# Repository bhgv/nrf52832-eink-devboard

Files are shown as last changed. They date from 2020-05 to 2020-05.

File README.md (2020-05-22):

designed mainly for custom nrf52832 (E73-2G4M04S1B module) + e-Ink screen based
smart-clock 

Eagle CAD PCB in the /pcb folder

tested with 2 and 4 colors waveshare/goodisplay SPI e-Incs: 2.7", 2.3", 2.9". glass based & flexible

software part (IAR 7.7) with drivers for flexible e-ink 2.9" partially refresh (no black screens between drawings/refreshes), 
graphics, font, etc.
yet it is experimental.

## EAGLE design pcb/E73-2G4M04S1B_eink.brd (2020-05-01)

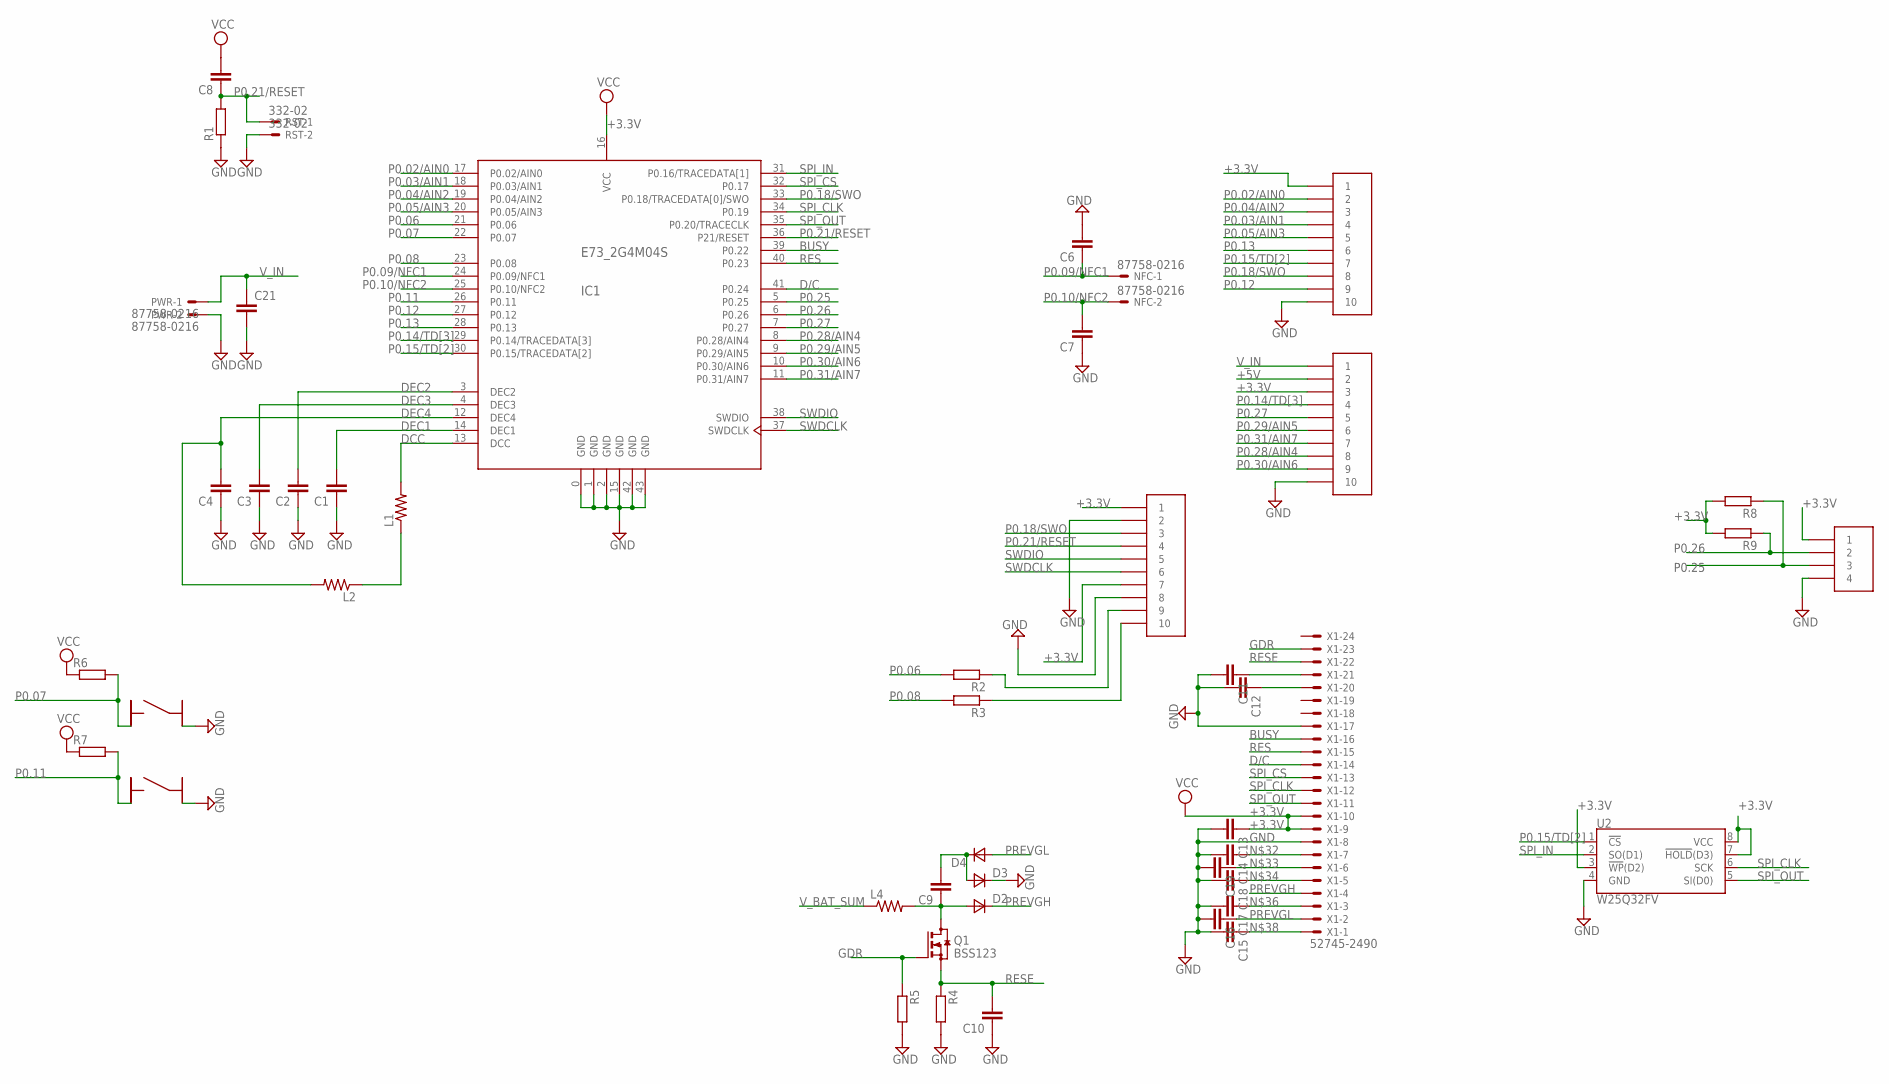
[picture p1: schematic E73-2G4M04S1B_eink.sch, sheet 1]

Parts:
C1, C2, C3, C4, C6, C7, C8, C9, C10, C11, C12, C13, C14, C15, C16, C17, C18, C19: C-EUC0603; C0603
C21: C-EUC0805; C0805
D2, D3, D4: DSOD323; SOD323
DBG-COM, DBG-COM1, DBG-COM2: HDR-1.27MM-110; HDR-1.27MM-1*10
IC1: E73_2G4M04S
L1, L2, L4: R-US_R0805; R0805
NFC: 87758-0216
PWR: 87758-0216
Q1: BSS123; SOT23
R1, R2, R3, R4, R5, R6, R7, R8, R9: R-EU_R0603; R0603
RST: 332-02
U2: W25Q32FV; SOIC-8
U$3: HDR-1.27MM-14; HDR-1.27MM-1*4
U$4, U$5: BUTTON_3X3MM_4PINS; BUT_3X3_4PINS
X1: 52745-2490

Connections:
+3.3V: C8.2, C13.1, DBG-COM.P$1 (1), DBG-COM.P$7 (7), DBG-COM1.P$1 (1), DBG-COM2.P$3 (3), IC1.16 (VCC), R6.1, R7.1, R8.2, R9.2, U2.3 (!WP!(D2)), U2.7 (!HOLD!(D3)), U2.8 (VCC), U$3.P$1 (1), X1.9, X1.10; also elsewhere on the board
+5V: DBG-COM2.P$2 (2); also elsewhere on the board
BUSY: IC1.39 (P0.22), X1.16
D/C: IC1.41 (P0.24), X1.14
DCC: IC1.13 (DCC), L1.2
DEC1: C1.2, IC1.14 (DEC1)
DEC2: C2.2, IC1.3 (DEC2)
DEC3: C3.2, IC1.4 (DEC3)
DEC4: C4.2, IC1.12 (DEC4), L2.2
GDR: Q1.1 (G), R5.1, X1.23
GND: C1.1, C2.1, C3.1, C4.1, C6.2, C7.1, C10.1, C11.2, C12.2, C13.2, C14.2, C15.2, C16.2, C17.2, C18.2, C19.2, C21.2, D3.1 (C), DBG-COM.P$2 (2), DBG-COM.P$8 (8), DBG-COM1.P$10 (10), DBG-COM2.P$10 (10), IC1.0 (GND), IC1.1 (GND), IC1.2 (GND), IC1.15 (GND), IC1.42 (GND), IC1.43 (GND), PWR.2, R1.1, R4.2, R5.2, RST.2, U2.4 (GND), U$3.P$4 (4), U$4.P$2, U$5.P$2, X1.8, X1.17; also elsewhere on the board
unnamed: DBG-COM.P$10 (10), R3.1
unnamed: L1.1, L2.1
unnamed: DBG-COM.P$9 (9), R2.1
unnamed: C9.1, D2.2 (A), L4.2, Q1.3 (D)
unnamed: C9.2, D3.2 (A), D4.1 (C)
unnamed: C11.1, X1.21
unnamed: C12.1, X1.20
unnamed: C14.1, X1.7
unnamed: C19.1, X1.6
unnamed: C18.1, X1.5
unnamed: C17.1, X1.3
unnamed: C15.1, X1.1
P0.02/AIN0: DBG-COM1.P$2 (2), IC1.17 (P0.02/AIN0)
P0.03/AIN1: DBG-COM1.P$4 (4), IC1.18 (P0.03/AIN1)
P0.04/AIN2: DBG-COM1.P$3 (3), IC1.19 (P0.04/AIN2)
P0.05/AIN3: DBG-COM1.P$5 (5), IC1.20 (P0.05/AIN3)
P0.06: IC1.21 (P0.06), R2.2
P0.07: IC1.22 (P0.07), R6.2, U$4.P$1
P0.08: IC1.23 (P0.08), R3.2
P0.09/NFC1: C6.1, IC1.24 (P0.09/NFC1), NFC.1
P0.10/NFC2: C7.2, IC1.25 (P0.10/NFC2), NFC.2
P0.11: IC1.26 (P0.11), R7.2, U$5.P$1
P0.12: DBG-COM1.P$9 (9), IC1.27 (P0.12)
P0.13: DBG-COM1.P$6 (6), IC1.28 (P0.13)
P0.14/TD[3]: DBG-COM2.P$4 (4), IC1.29 (P0.14/TRACEDATA[3])
P0.15/TD[2]: DBG-COM1.P$7 (7), IC1.30 (P0.15/TRACEDATA[2]), U2.1 (!CS!)
P0.18/SWO: DBG-COM.P$3 (3), DBG-COM1.P$8 (8), IC1.33 (P0.18/TRACEDATA[0]/SWO)
P0.21/RESET: C8.1, DBG-COM.P$4 (4), IC1.36 (P21/RESET), R1.2, RST.1
P0.25: IC1.5 (P0.25), R8.1, U$3.P$3 (3)
P0.26: IC1.6 (P0.26), R9.1, U$3.P$2 (2)
P0.27: DBG-COM2.P$5 (5), IC1.7 (P0.27)
P0.28/AIN4: DBG-COM2.P$8 (8), IC1.8 (P0.28/AIN4)
P0.29/AIN5: DBG-COM2.P$6 (6), IC1.9 (P0.29/AIN5)
P0.30/AIN6: DBG-COM2.P$9 (9), IC1.10 (P0.30/AIN6)
P0.31/AIN7: DBG-COM2.P$7 (7), IC1.11 (P0.31/AIN7)
PREVGH: D2.1 (C), X1.4
PREVGL: C16.1, D4.2 (A), X1.2
RES: IC1.40 (P0.23), X1.15
RESE: C10.2, Q1.2 (S), R4.1, X1.22
SPI_CLK: IC1.34 (P0.19), U2.6 (SCK), X1.12
SPI_CS: IC1.32 (P0.17), X1.13
SPI_IN: IC1.31 (P0.16/TRACEDATA[1]), U2.2 (SO(D1))
SPI_OUT: IC1.35 (P0.20/TRACECLK), U2.5 (SI(D0)), X1.11
SWDCLK: DBG-COM.P$6 (6), IC1.37 (SWDCLK)
SWDIO: DBG-COM.P$5 (5), IC1.38 (SWDIO)
V_BAT_SUM: L4.1; also elsewhere on the board
V_IN: C21.1, DBG-COM2.P$1 (1), PWR.1; also elsewhere on the board

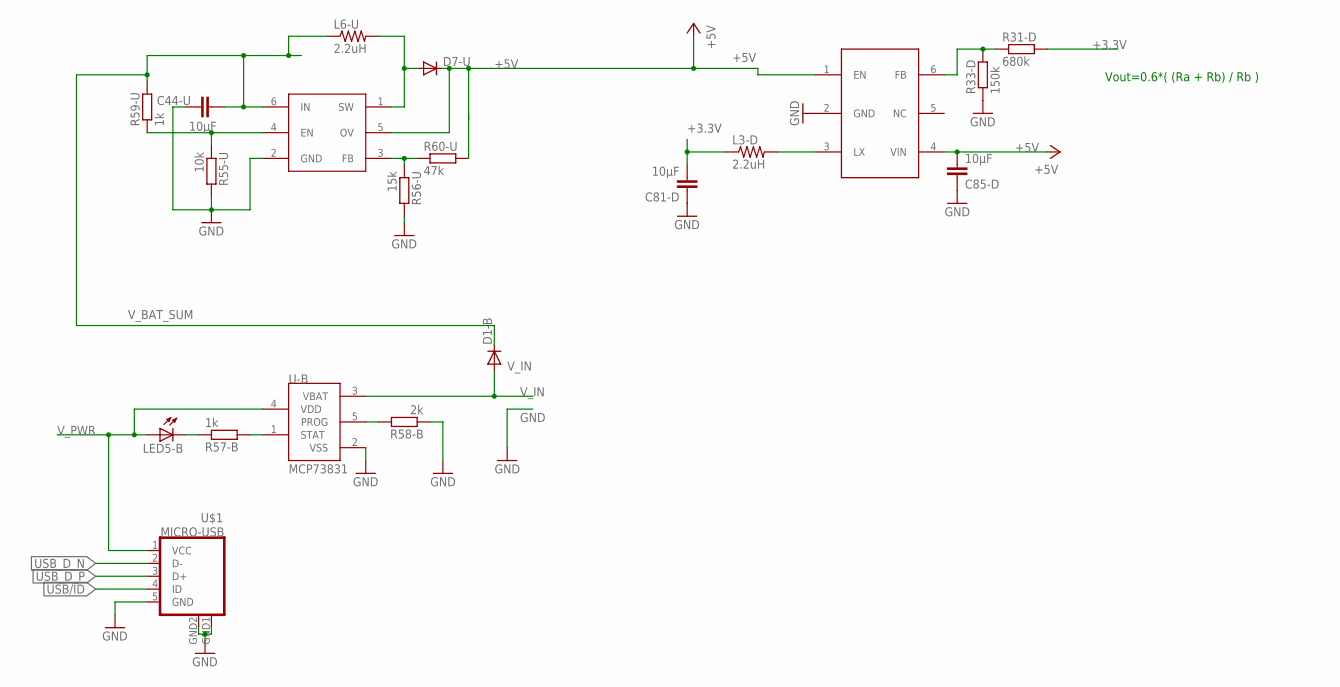
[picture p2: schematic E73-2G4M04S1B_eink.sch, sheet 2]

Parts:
C44-U, C81-D, C85-D: 10µF; C0805
D1-B, D7-U: DIODE-SOD323-W; SOD323-W
L3-D, L6-U: 2.2uH; R0805
LED5-B: LEDCHIPLED_0805; CHIPLED_0805
R31-D: 680k; R0603
R33-D: 150k; R0603
R55-U: 10k; R0603
R56-U: 15k; R0603
R57-B, R59-U: 1k; R0603
R58-B: 2k; R0603
R60-U: 47k; R0603
U$1: MICRO-USB
U-B: MCP73831; SOT23-5L
U-D: STI3411; SOT23-6
U-U: PT4101; SOT23-6

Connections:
+3.3V: C81-D.2, L3-D.1, R31-D.2; also elsewhere on the board
+5V: C85-D.2, D7-U.C, R60-U.2, U-D.1 (EN), U-D.4 (VIN), U-U.5 (OV); also elsewhere on the board
GND: C44-U.2, C81-D.1, C85-D.1, R33-D.1, R55-U.2, R56-U.2, R58-B.1, U$1.5 (GND), U$1.GND1 (GND), U$1.GND2 (GND), U-B.2 (VSS), U-D.2 (GND), U-U.2 (GND); also elsewhere on the board
unnamed: R56-U.1, R60-U.1, U-U.3 (FB)
unnamed: R55-U.1, R59-U.1, U-U.4 (EN)
unnamed: D7-U.A, L6-U.2, U-U.1 (SW)
unnamed: L3-D.2, U-D.3 (LX)
unnamed: R31-D.1, R33-D.2, U-D.6 (FB)
unnamed: R58-B.2, U-B.5 (PROG)
unnamed: R57-B.2, U-B.1 (STAT)
unnamed: LED5-B.C, R57-B.1
USB/ID: U$1.4 (ID)
USB_D_N: U$1.2 (D-)
USB_D_P: U$1.3 (D+)
V_BAT_SUM: C44-U.1, D1-B.C, L6-U.1, R59-U.2, U-U.6 (IN); also elsewhere on the board
V_IN: D1-B.A, U-B.3 (VBAT); also elsewhere on the board
V_PWR: LED5-B.A, U$1.1 (VCC), U-B.4 (VDD)

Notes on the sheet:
Vout=0.6*( (Ra + Rb) / Rb )

Board: 2 copper layers, 67 parts (48 on the bottom side), 67 nets, no tracks yet.

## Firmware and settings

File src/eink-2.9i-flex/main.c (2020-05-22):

/**
 * Copyright (c) 2015 - 2018, Nordic Semiconductor ASA
 *
 * All rights reserved.
 *
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
 * 3. Neither the name of Nordic Semiconductor ASA nor the names of its
 *    contributors may be used to endorse or promote products derived from this
 *    software without specific prior written permission.
 *
 * 4. This software, with or without modification, must only be used with a
 *    Nordic Semiconductor ASA integrated circuit.
 *
 * 5. Any software provided in binary form under this license must not be reverse
 *    engineered, decompiled, modified and/or disassembled.
 *
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
 */
#include "nrf_drv_spi.h"
#include "app_util_platform.h"
#include "nrf_gpio.h"
#include "nrf_delay.h"
#include "boards.h"
#include "app_error.h"
#include <string.h>
#include "nrf_log.h"
#include "nrf_log_ctrl.h"
#include "nrf_log_default_backends.h"

#include "nrf_gpiote.h"
#include "nrf_drv_ppi.h"
#include "nrf_drv_timer.h"
#include "nrf_drv_gpiote.h"

#include "nrf_delay.h"

#include "main.h"

#define COMPRESSED

#include "xbm_font.h"
#include "User/XBM/fonts/DINNextW1G_Light_[58]_xbm_font.h"
#include "User/XBM/fonts/DINNextW1G_Light_[127]_xbm_font.h"

#include "User/XBM/fonts/LCD_[124]_xbm_font.h"


#include "User/XBM/fonts/TMVinograd_[70]_xbm_font.h"
#include "User/XBM/fonts/BNHRDFAN_[50]_xbm_font.h"
#include "User/XBM/fonts/BNKGOTHM_[60]_xbm_font.h"
#include "User/XBM/fonts/GOST_A__[62]_xbm_font.h"

#include "User/XBM/fonts/ACLine_[100]_xbm_font.h"
#include "User/XBM/fonts/BNHRDFAN_[50]_xbm_font.h"
#include "User/XBM/fonts/CaviarDreams_[100]_xbm_font.h"
#include "User/XBM/fonts/Lasco_[100]_xbm_font.h"
#include "User/XBM/fonts/OpenSans_[100]_xbm_font.h"
#include "User/XBM/fonts/Ubuntu_[100]_xbm_font.h"
#include "User/XBM/fonts/Alexander_[100]_xbm_font.h"
#include "User/XBM/fonts/BNHRDMBI_[100]_xbm_font.h"
#include "User/XBM/fonts/DINNextW1G_Light_[127]_xbm_font.h"
#include "User/XBM/fonts/LCD_[100]_xbm_font.h"
#include "User/XBM/fonts/Raleway_[100]_xbm_font.h"
#include "User/XBM/fonts/ALLEGRON_[100]_xbm_font.h"
#include "User/XBM/fonts/BNHRDMOB_[100]_xbm_font.h"
#include "User/XBM/fonts/DINNextW1G_Light_[58]_xbm_font.h"
#include "User/XBM/fonts/LCD_[124]_xbm_font.h"
#include "User/XBM/fonts/RobotoCondensed_[100]_xbm_font.h"
#include "User/XBM/fonts/Bender_[100]_xbm_font.h"
#include "User/XBM/fonts/BNKGOTHM_[100]_xbm_font.h"
#include "User/XBM/fonts/gnyrwn971_[100]_xbm_font.h"
#include "User/XBM/fonts/LEngineer_[100]_xbm_font.h"
#include "User/XBM/fonts/TMVinograd_[100]_xbm_font.h"
#include "User/XBM/fonts/BNHRDFAN_[100]_xbm_font.h"
#include "User/XBM/fonts/BNKGOTHM_[60]_xbm_font.h"
#include "User/XBM/fonts/GOST_A__[100]_xbm_font.h"
#include "User/XBM/fonts/NotoSans_[100]_xbm_font.h"
#include "User/XBM/fonts/TMVinograd_[70]_xbm_font.h"

#include <stdio.h>

//#include "ImageData.h"
#include "User/GUI/GUI_Paint.h"
#include "User/e-Paper/EPD_2in7.h"


#define SPI_INSTANCE  0 /**< SPI instance index. */
static const nrf_drv_spi_t spi = NRF_DRV_SPI_INSTANCE(SPI_INSTANCE);  /**< SPI instance. */
static volatile bool spi_xfer_done = true;  /**< Flag used to indicate that SPI instance completed the transfer. */

#define TEST_STRING "Nordic"
//static uint8_t       m_tx_buf[] = TEST_STRING;           /**< TX buffer. */
static uint8_t       m_rx_buf[sizeof(TEST_STRING) + 1];    /**< RX buffer. */
//static const uint8_t m_length = sizeof(m_tx_buf);        /**< Transfer length. */








////////////////////////////////Picture demonstration///////////////////////////////////
////////////////////////////////////////////////////////////////////////////////////////
//296*128   16 gray picture
const unsigned char gImage_1[18944] = { /* 0X81,0X04,0X28,0X01,0X80,0X00, */
0XFF,0XFF,0XFF,0XFF,0XFF,0XFF,0XFF,0XFF,0XFF,0XFF,0XFF,0XFF,0XFF,0XFF,0XFF,0XFF,
0XFF,0XFF,0XFF,0XFF,0XFF,0XFF,0XFF,0XFF,0XFF,0XFF,0XFF,0XFF,0XFF,0XFF,0XFF,0XFF,
0XFF,0XFF,0XFF,0XFF,0XFF,0XFF,0XFF,0XFF,0XFF,0XFF,0XFF,0XFF,0XFF,0XFF,0XFF,0XFF,
0XFF,0XFF,0XFF,0XFF,0XFF,0XFF,0XFF,0XFF,0XFF,0XFF,0XFF,0XFF,0XFF,0XFF,0XFF,0XFF,
0XFF,0XFF,0XFF,0XFF,0XFF,0XFF,0XFF,0XFF,0XFF,0XFF,0XFF,0XFF,0XFF,0XFF,0XFF,0XFF,
0XFF,0XFF,0XFF,0XFF,0XFF,0XFF,0XFF,0XFF,0XFF,0XFF,0XFF,0XFF,0XFF,0XFF,0XFF,0XFF,
0XFF,0XFF,0XFF,0XFF,0XFF,0XFF,0XFF,0XFF,0XFF,0XFF,0XFF,0XFF,0XFF,0XFF,0XFF,0XFF,
0XFF,0XFF,0XFF,0XFF,0XFF,0XFF,0XFF,0XFF,0XFF,0XFF,0XFF,0XFF,0XFF,0XFF,0XFF,0XFF,
0XFF,0XFF,0XFF,0XFF,0XFF,0XFF,0XFF,0XFF,0XFF,0XFF,0XFF,0XFF,0XFF,0XFF,0XFF,0XFF,
0XFF,0XFF,0XFF,0XFF,0XFF,0XFF,0XFF,0XFF,0XFF,0XFF,0XFF,0XFF,0XFF,0XFF,0XFF,0XFF,
0XFF,0XFF,0XFF,0XFF,0XFF,0XFF,0XFF,0XFF,0XFF,0XFF,0XFF,0XFF,0XFF,0XFF,0XFF,0XFF,
0XFF,0XFF,0XFF,0XFF,0XFF,0XFF,0XFF,0XFF,0XFF,0XFF,0XFF,0XFF,0XFF,0XFF,0XFF,0XFF,
0XFF,0XFF,0XFF,0XFF,0XFF,0XFF,0XFF,0XFF,0XFF,0XFF,0XFF,0XFF,0XFF,0XFF,0XFF,0XFF,
0XFF,0XFF,0XFF,0XFF,0XFF,0XFF,0XFF,0XFF,0XFF,0XFF,0XFF,0XFF,0XFF,0XFF,0XFF,0XFF,
0XFF,0XFF,0XFF,0XFF,0XFF,0XFF,0XFF,0XFF,0XFF,0XFF,0XFF,0XFF,0XFF,0XFF,0XFF,0XFF,
0XFF,0XFF,0XFF,0XFF,0XFF,0XFF,0XFF,0XFF,0XFF,0XFF,0XFF,0XFF,0XFF,0XFF,0XFF,0XFF,
0XFF,0XFF,0XFF,0XFF,0XFF,0XFF,0XFF,0XFF,0XFF,0XFF,0XFF,0XFF,0XFF,0XFF,0XFF,0XFF,
0XFF,0XFF,0XFF,0XFF,0XFF,0XFF,0XFF,0XFF,0XFF,0XFF,0XFF,0XFF,0XFF,0XFF,0XFF,0XFF,
0XFF,0XFF,0XFF,0XFF,0XFF,0XFF,0XFF,0XFF,0XFF,0XFF,0XFF,0XFF,0XFF,0XFF,0XFF,0XFF,
0XFF,0XFF,0XFF,0XFF,0XFF,0XFF,0XFF,0XFF,0XFF,0XFF,0XFF,0XFF,0XFF,0XFF,0XFF,0XFF,
0XFF,0XFF,0XFF,0XFF,0XFF,0XFF,0XFF,0XFF,0XFF,0XFF,0XFF,0XFF,0XFF,0XFF,0XFF,0XFF,
0XFF,0XFF,0XFF,0XFF,0XFF,0XFF,0XFF,0XFF,0XFF,0XFF,0XFF,0XFF,0XFF,0XFF,0XFF,0XFF,
0XFF,0XFF,0XFF,0XFF,0XFF,0XFF,0XFF,0XFF,0XFF,0XFF,0XFF,0XFF,0XFF,0XFF,0XFF,0XFF,
0XFF,0XFF,0XFF,0XFF,0XFF,0XFF,0XFF,0XFF,0XFF,0XFF,0XFF,0XFF,0XFF,0XFF,0XFF,0XFF,
0XFF,0XFF,0XFF,0XFF,0XFF,0XFF,0XFF,0XFF,0XFF,0XFF,0XFF,0XFF,0XFF,0XFF,0XFF,0XFF,
0XFF,0XFF,0XFF,0XFF,0XFF,0XFF,0XFF,0XFF,0XFF,0XFF,0XFF,0XFF,0XFF,0XFF,0XFF,0XFF,
0XFF,0XFF,0XFF,0XFF,0XFF,0XFF,0XFF,0XFF,0XFF,0XFF,0XFF,0XFF,0XFF,0XFF,0XFF,0XFF,
0XFF,0XFF,0XFF,0XFF,0XFF,0XFF,0XFF,0XFF,0XFF,0XFF,0XFF,0XFF,0XFF,0XFF,0XFF,0XFF,
0XFF,0XFF,0XFF,0XFF,0XFF,0XFF,0XFF,0XFF,0XFF,0XFF,0XFF,0XFF,0XFF,0XFF,0XFF,0XFF,
0XFF,0XFF,0XFF,0XFF,0XFF,0XFF,0XFF,0XFF,0XFF,0XFF,0XFF,0XFF,0XFF,0XFF,0XFF,0XFF,
0XFF,0XFF,0XFF,0XFF,0XFF,0XFF,0XFF,0XFF,0XFF,0XFF,0XFF,0XFF,0XFF,0XFF,0XFF,0XFF,
0XFF,0XFF,0XFF,0XFF,0XFF,0XFF,0XFF,0XFF,0XFF,0XFF,0XFF,0XFF,0XFF,0XFF,0XFF,0XFF,
0XFF,0XFF,0XFF,0XFF,0XFF,0XFF,0XFF,0XFF,0XFF,0XFF,0XFF,0XFF,0XFF,0XFF,0XFF,0XFF,
0XFF,0XFF,0XFF,0XFF,0XFF,0XFF,0XFF,0XFF,0XFF,0XFF,0XFF,0XFF,0XFF,0XFF,0XFF,0XFF,
0XFF,0XFF,0XFF,0XFF,0XFF,0XFF,0XFF,0XFF,0XFF,0XFF,0XFF,0XFF,0XFF,0XFF,0XFF,0XFF,
0XFF,0XFF,0XFF,0XFF,0XFF,0XFF,0XFF,0XFF,0XFF,0XFF,0XFF,0XFF,0XFF,0XFF,0XFF,0XFF,
0XFF,0XFF,0XFF,0XFF,0XFF,0XFF,0XFF,0XFF,0XFF,0XFF,0XFF,0XFF,0XFF,0XFF,0XFF,0XFF,
0XFF,0XFF,0XFF,0XFF,0XFF,0XFF,0XFF,0XFF,0XFF,0XFF,0XFF,0XFF,0XFF,0XFF,0XFF,0XFF,
0XFF,0XFF,0XFF,0XFF,0XFF,0XFF,0XFF,0XFF,0XFF,0XFF,0XFF,0XFF,0XFF,0XFF,0XFF,0XFF,
0XFF,0XFF,0XFF,0XFF,0XFF,0XFF,0XFF,0XFF,0XFF,0XFF,0XFF,0XFF,0XFF,0XFF,0XFF,0XFF,
0XFF,0XFF,0XFF,0XFF,0XFF,0XFF,0XFF,0XFF,0XFF,0XFF,0XFF,0XFF,0XFF,0XFF,0XFF,0XFF,
0XFF,0XFF,0XFF,0XFF,0XFF,0XFF,0XFF,0XFF,0XFF,0XFF,0XFF,0XFF,0XFF,0XFF,0XFF,0XFF,
0XFF,0XFF,0XFF,0XFF,0XFF,0XFF,0XFF,0XFF,0XFF,0XFF,0XFF,0XFF,0XFF,0XFF,0XFF,0XFF,
0XFF,0XFF,0XFF,0XFF,0XFF,0XFF,0XFF,0XFF,0XFF,0XFF,0XFF,0XFF,0XFF,0XFF,0XFF,0XFF,
0XFF,0XFF,0XFF,0XFF,0XFF,0XFF,0XFF,0XFF,0XFF,0XFF,0XFF,0XFF,0XFF,0XFF,0XFF,0XFF,
0XFF,0XFF,0XFF,0XFF,0XFF,0XFF,0XFF,0XFF,0XFF,0XFF,0XFF,0XFF,0XFF,0XFF,0XFF,0XFF,
0XFF,0XFF,0XFF,0XFF,0XFF,0XFF,0XFF,0XFF,0XFF,0XFF,0XFF,0XFF,0XFF,0XFF,0XFF,0XFF,
0XFF,0XFF,0XFF,0XFF,0XFF,0XFF,0XFF,0XFF,0XFF,0XFF,0XFF,0XFF,0XFF,0XFF,0XFF,0XFF,
0XFF,0XFF,0XFF,0XFF,0XFF,0XFF,0XFF,0XFF,0XFF,0XFF,0XFF,0XFF,0XFF,0XFF,0XFF,0XFF,
0XFF,0XFF,0XFF,0XFF,0XFF,0XFF,0XFF,0XFF,0XFF,0XFF,0XFF,0XFF,0XFF,0XFF,0XFF,0XFF,
0XFF,0XFF,0XFF,0XFF,0XFF,0XFF,0XFF,0XFF,0XFF,0XFF,0XFF,0XFF,0XFF,0XFF,0XFF,0XFF,
0XFF,0XFF,0XFF,0XFF,0XFF,0XFF,0XFF,0XFF,0XFF,0XFF,0XFF,0XFF,0XFF,0XFF,0XFF,0XFF,
0XFF,0XFF,0XFF,0XFF,0XFF,0XFF,0XFF,0XFF,0XFF,0XFF,0XFF,0XFF,0XFF,0XFF,0XFF,0XFF,
0XFF,0XFF,0XFF,0XFF,0XFF,0XFF,0XFF,0XFF,0XFF,0XFF,0XFF,0XFF,0XFF,0XFF,0XFF,0XFF,
0XFF,0XFF,0XFF,0XFF,0XFF,0XFF,0XFF,0XFF,0XFF,0XFF,0XFF,0XFF,0XFF,0XFF,0XFF,0XFF,
0XFF,0XFF,0XFF,0XFF,0XFF,0XFF,0XFF,0XFF,0XFF,0XFF,0XFF,0XFF,0XFF,0XFF,0XFF,0XFF,
0XFF,0XFF,0XFF,0XFF,0XFF,0XFF,0XFF,0XFF,0XFF,0XFF,0XFF,0XFF,0XFF,0XFF,0XFF,0XFF,
0XFF,0XFF,0XFF,0XFF,0XFF,0XFF,0XFF,0XFF,0XFF,0XFF,0XFF,0XFF,0XFF,0XFF,0XFF,0XFF,
0XFF,0XFF,0XFF,0XFF,0XFF,0XFF,0XFF,0XFF,0XFF,0XFF,0XFF,0XFF,0XFF,0XFF,0XFF,0XFF,
0XFF,0XFF,0XFF,0XFF,0XFF,0XFF,0XFF,0XFF,0XFF,0XFF,0XFF,0XFF,0XFF,0XFF,0XFF,0XFF,
0XFF,0XFF,0XFF,0XFF,0XFF,0XFF,0XFF,0XFF,0XFF,0XFF,0XFF,0XFF,0XFF,0XFF,0XFF,0XFF,
0XFF,0XFF,0XFF,0XFF,0XFF,0XFF,0XFF,0XFF,0XFF,0XFF,0XFF,0XFF,0XFF,0XFF,0XFF,0XFF,
0XFF,0XFF,0XFF,0XFF,0XFF,0XFF,0XFF,0XFF,0XFF,0XFF,0XFF,0XFF,0XFF,0XFF,0XFF,0XFF,
0XFF,0XFF,0XFF,0XFF,0XFF,0XFF,0XFF,0XFF,0XFF,0XFF,0XFF,0XFF,0XFF,0XFF,0XFF,0XFF,
0XFF,0XFF,0XFF,0XFF,0XFF,0XFF,0XFF,0XFF,0XFF,0XFF,0XFF,0XFF,0XFF,0XFF,0XFF,0XFF,
0XFF,0XFF,0XFF,0XFF,0XFF,0XFF,0XFF,0XFF,0XFF,0XFF,0XFF,0XFF,0XFF,0XFF,0XFF,0XFF,
0XFF,0XFF,0XFF,0XFF,0XFF,0XFF,0XFF,0XFF,0XFF,0XFF,0XFF,0XFF,0XFF,0XFF,0XFF,0XFF,
0XFF,0XFF,0XFF,0XFF,0XFF,0XFF,0XFF,0XFF,0XFF,0XFF,0XFF,0XFF,0XFF,0XFF,0XFF,0XFF,
0XFF,0XFF,0XFF,0XFF,0XFF,0XFF,0XFF,0XFF,0XFF,0XFF,0XFF,0XFF,0XFF,0XFF,0XFF,0XFF,
0XFF,0XFF,0XFF,0XFF,0XFF,0XFF,0XFF,0XFF,0XFF,0XFF,0XFF,0XFF,0XFF,0XFF,0XFF,0XFF,
0XFF,0XFF,0XFF,0XFF,0XFF,0XFF,0XFF,0XFF,0XFF,0XFF,0XFF,0XFF,0XFF,0XFF,0XFF,0XFF,
0XFF,0XFF,0XFF,0XFF,0XFF,0XFF,0XFF,0XFF,0XFF,0XFF,0XFF,0XFF,0XFF,0XFF,0XFF,0XFF,
0XFF,0XFF,0XFF,0XFF,0XFF,0XFF,0XFF,0XFF,0XFF,0XFF,0XFF,0XFF,0XFF,0XFF,0XFF,0XFF,
0XFF,0XFF,0XFF,0XFF,0XFF,0XFF,0XFF,0XFF,0XFF,0XFF,0XFF,0XFF,0XFF,0XFF,0XFF,0XFF,
0XFF,0XFF,0XFF,0XFF,0XFF,0XFF,0XFF,0XFF,0XFF,0XFF,0XFF,0XFF,0XFF,0XFF,0XFF,0XFF,
0XFF,0XFF,0XFF,0XFF,0XFF,0XFF,0XFF,0XFF,0XFF,0XFF,0XFF,0XFF,0XFF,0XFF,0XFF,0XFF,
0XFF,0XFF,0XFF,0XFF,0XFF,0XFF,0XFF,0XFF,0XFF,0XFF,0XFF,0XFF,0XFF,0XFF,0XFF,0XFF,
0XFF,0XFF,0XFF,0XFF,0XFF,0XFF,0XFF,0XFF,0XFF,0XFF,0XFF,0XFF,0XFF,0XFF,0XFF,0XFF,
0XFF,0XFF,0XFF,0XFF,0XFF,0XFF,0XFF,0XFF,0XFF,0XFF,0XFF,0XFF,0XFF,0XFF,0XFF,0XFF,
0XFF,0XFF,0XFF,0XFF,0XFF,0XFF,0XFF,0XFF,0XFF,0XFF,0XFF,0XFF,0XFF,0XFF,0XFF,0XFF,
0XFF,0XFF,0XFF,0XFF,0XFF,0XFF,0XFF,0XFF,0XFF,0XFF,0XFF,0XFF,0XFF,0XFF,0XFF,0XFF,
0XFF,0XFF,0XFF,0XFF,0XFF,0XFF,0XFF,0XFF,0XFF,0XFF,0XFF,0XFF,0XFF,0XFF,0XFF,0XFF,
0XFF,0XFF,0XFF,0XFF,0XFF,0XFF,0XFF,0XFF,0XFF,0XFF,0XFF,0XFF,0XFF,0XFF,0XFF,0XFF,
0XFF,0XFF,0XFF,0XFF,0XFF,0XFF,0XFF,0XFF,0XFF,0XFF,0XFF,0XFF,0XFF,0XFF,0XFF,0XFF,
0XFF,0XFF,0XFF,0XFF,0XFF,0XFF,0XFF,0XFF,0XFF,0XFF,0XFF,0XFF,0XFF,0XFF,0XFF,0XFF,
0XFF,0XFF,0XFF,0XFF,0XFF,0XFF,0XFF,0XFF,0XFF,0XFF,0XFF,0XFF,0XFF,0XFF,0XFF,0XFF,
0XFF,0XFF,0XFF,0XFF,0XFF,0XFF,0XFF,0XFF,0XFF,0XFF,0XFF,0XFF,0XFF,0XFF,0XFF,0XFF,
0XFF,0XFF,0XFF,0XFF,0XFF,0XFF,0XFF,0XFF,0XFF,0XFF,0XFF,0XFF,0XFF,0XFF,0XFF,0XFF,
0XFF,0XFF,0XFF,0XFF,0XFF,0XFF,0XFF,0XFF,0XFF,0XFF,0XFF,0XFF,0XFF,0XFF,0XFF,0XFF,
0XFF,0XFF,0XFF,0XFF,0XFF,0XFF,0XFF,0XFF,0XFF,0XFF,0XFF,0XFF,0XFF,0XFF,0XFF,0XFF,
0XFF,0XFF,0XFF,0XFF,0XFF,0XFF,0XFF,0XFF,0XFF,0XFF,0XFF,0XFF,0XFF,0XFF,0XFF,0XFF,
0XFF,0XFF,0XFF,0XFF,0XFF,0XFF,0XFF,0XFF,0XFF,0XFF,0XFF,0XFF,0XFF,0XFF,0XFF,0XFF,
0XFF,0XFF,0XFF,0XFF,0XFF,0XFF,0XFF,0XFF,0XFF,0XFF,0XFF,0XFF,0XFF,0XFF,0XFF,0XFF,
0XFF,0XFF,0XFF,0XFF,0XFF,0XFF,0XFF,0XFF,0XFF,0XFF,0XFF,0XFF,0XFF,0XFF,0XFF,0XFF,
0XFF,0XFF,0XFF,0XFF,0XFF,0XFF,0XFF,0XFF,0XFF,0XFF,0XFF,0XFF,0XFF,0XFF,0XFF,0XFF,
0XFF,0XFF,0XFF,0XFF,0XFF,0XFF,0XFF,0XFF,0XFF,0XFF,0XFF,0XFF,0XFF,0XFF,0XFF,0XFF,
0XFF,0XFF,0XFF,0XFF,0XFF,0XFF,0XFF,0XFF,0XFF,0XFF,0XFF,0XFF,0XFF,0XFF,0XFF,0XFF,
0XFF,0XFF,0XFF,0XFF,0XFF,0XFF,0XFF,0XFF,0XFF,0XFF,0XFF,0XFF,0XFF,0XFF,0XFF,0XFF,
0XFF,0XFF,0XFF,0XFF,0XFF,0XFF,0XFF,0XFF,0XFF,0XFF,0XFF,0XFF,0XFF,0XFF,0XFF,0XFF,
0XFF,0XFF,0XFF,0XFF,0XFF,0XFF,0XFF,0XFF,0XFF,0XFF,0XFF,0XFF,0XFF,0XFF,0XFF,0XFF,
0XFF,0XFF,0XFF,0XFF,0XFF,0XFF,0XFF,0XFF,0XFF,0XFF,0XFF,0XFF,0XFF,0XFF,0XFF,0XFF,
0XFF,0XFF,0XFF,0XFF,0XFF,0XFF,0XFF,0XFF,0XFF,0XFF,0XFF,0XFF,0XFF,0XFF,0XFF,0XFF,
0XFF,0XFF,0XFF,0XFF,0XFF,0XFF,0XFF,0XFF,0XFF,0XFF,0XFF,0XFF,0XFF,0XFF,0XFF,0XFF,
0XFF,0XFF,0XFF,0XFF,0XFF,0XFF,0XFF,0XFF,0XFF,0XFF,0XFF,0XFF,0XFF,0XFF,0XFF,0XFF,
0XFF,0XFF,0XFF,0XFF,0XFF,0XFF,0XFF,0XFF,0XFF,0XFF,0XFF,0XFF,0XFF,0XFF,0XFF,0XFF,
0XFF,0XFF,0XFF,0XFF,0XFF,0XFF,0XFF,0XFF,0XFF,0XFF,0XFF,0XFF,0XFF,0XFF,0XFF,0XFF,
0XFF,0XFF,0XFF,0XFF,0XFF,0XFF,0XFF,0XFF,0XFF,0XFF,0XFF,0XFF,0XFF,0XFF,0XFF,0XFF,
0XFF,0XFF,0XFF,0XFF,0XFF,0XFF,0XFF,0XFF,0XFF,0XFF,0XFF,0XFF,0XFF,0XFF,0XFF,0XFF,
0XFF,0XFF,0XFF,0XFF,0XFF,0XFF,0XFF,0XFF,0XFF,0XFF,0XFF,0XFF,0XFF,0XFF,0XFF,0XFF,
0XFF,0XFF,0XFF,0XFF,0XFF,0XFF,0XFF,0XFF,0XFF,0XFF,0XFF,0XFF,0XFF,0XFF,0XFF,0XFF,
0XFF,0XFF,0XFF,0XFF,0XFF,0XFF,0XFF,0XFF,0XFF,0XFF,0XFF,0XFF,0XFF,0XFF,0XFF,0XFF,
0XFF,0XFF,0XFF,0XFF,0XFF,0XFF,0XFF,0XFF,0XFF,0XFF,0XFF,0XFF,0XFF,0XFF,0XFF,0XFF,
0XFF,0XFF,0XFF,0XFF,0XFF,0XFF,0XFF,0XFF,0XFF,0XFF,0XFF,0XFF,0XFF,0XFF,0XFF,0XFF,
0XFF,0XFF,0XFF,0XFF,0XFF,0XFF,0XFF,0XFF,0XFF,0XFF,0XFF,0XFF,0XFF,0XFF,0XFF,0XFF,
0XFF,0XFF,0XFF,0XFF,0XFF,0XFF,0XFF,0XFF,0XFF,0XFF,0XFF,0XFF,0XFF,0XFF,0XFF,0XFF,
0XFF,0XFF,0XFF,0XFF,0XFF,0XFF,0XFF,0XFF,0XFF,0XFF,0XFF,0XFF,0XFF,0XFF,0XFF,0XFF,
0XFF,0XFF,0XFF,0XFF,0XFF,0XFF,0XFF,0XFF,0XFF,0XFF,0XFF,0XFF,0XFF,0XFF,0XFF,0XFF,
0XFF,0XFF,0XFF,0XFF,0XFF,0XFF,0XFF,0XFF,0XFF,0XFF,0XFF,0XFF,0XFF,0XFF,0XFF,0XFF,
0XFF,0XFF,0XFF,0XFF,0XFF,0XFF,0XFF,0XFF,0XFF,0XFF,0XFF,0XFF,0XFF,0XFF,0XFF,0XFF,
0XFF,0XFF,0XFF,0XFF,0XFF,0XFF,0XFF,0XFF,0XFF,0XFF,0XFF,0XFF,0XFF,0XFF,0XFF,0XFF,
0XFF,0XFF,0XFF,0XFF,0XFF,0XFF,0XFF,0XFF,0XFF,0XFF,0XFF,0XFF,0XFF,0XFF,0XFF,0XFF,
0XFF,0XFF,0XFF,0XFF,0XFF,0XFF,0XFF,0XFF,0XFF,0XFF,0XFF,0XFF,0XFF,0XFF,0XFF,0XFF,
0XFF,0XFF,0XFF,0XFF,0XFF,0XFF,0XFF,0XFF,0XFF,0XFF,0XFF,0XFF,0XFF,0XFF,0XFF,0XFF,
0XFF,0XFF,0XFF,0XFF,0XFF,0XFF,0XFF,0XFF,0XFF,0XFF,0XFF,0XFF,0XFF,0XFF,0XFF,0XFF,
0XFF,0XFF,0XFF,0XFF,0XFF,0XFF,0XFF,0XFF,0XFF,0XFF,0XFF,0XFF,0XFF,0XFF,0XFF,0XFF,
0XFF,0XFF,0XFF,0XFF,0XFF,0XFF,0XFF,0XFF,0XFF,0XFF,0XFF,0XFF,0XFF,0XFF,0XFF,0XFF,
0XFF,0XFF,0XFF,0XFF,0XFF,0XFF,0XFF,0XFF,0XFF,0XFF,0XFF,0XFF,0XFF,0XFF,0XFF,0XFF,
0XFF,0XFF,0XFF,0XFF,0XFF,0XFF,0XFF,0XFF,0XFF,0XFF,0XFF,0XFF,0XFF,0XFF,0XFF,0XFF,
0XFF,0XFF,0XFF,0XFF,0XFF,0XFF,0XFF,0XFF,0XFF,0XFF,0XFF,0XFF,0XFF,0XFF,0XFF,0XFF,
0XFF,0XFF,0XFF,0XFF,0XFF,0XFF,0XFF,0XFF,0XFF,0XFF,0XFF,0XFF,0XFF,0XFF,0XFF,0XFF,
0XFF,0XFF,0XFF,0XFF,0XFF,0XFF,0XFF,0XFF,0XFF,0XFF,0XFF,0XFF,0XFF,0XFF,0XFF,0XFF,
0XFF,0XFF,0XFF,0XFF,0XFF,0XFF,0XFF,0XFF,0XFF,0XFF,0XFF,0XFF,0XFF,0XFF,0XFF,0XFF,
0XFF,0XFF,0XFF,0XFF,0XFF,0XFF,0XFF,0XFF,0XFF,0XFF,0XFF,0XFF,0XFF,0XFF,0XFF,0XFF,
0XFF,0XFF,0XFF,0XFF,0XFF,0XFF,0XFF,0XFF,0XFF,0XFF,0XFF,0XFF,0XFF,0XFF,0XFF,0XFF,
0XFF,0XFF,0XFF,0XFF,0XFF,0XFF,0XFF,0XFF,0XFF,0XFF,0XFF,0XFF,0XFF,0XFF,0XFF,0XFF,
0XFF,0XFF,0XFF,0XFF,0XFF,0XFF,0XFF,0XFF,0XFF,0XFF,0XFF,0XFF,0XFF,0XFF,0XFF,0XFF,
0XFF,0XFF,0XFF,0XFF,0XFF,0XFF,0XFF,0XFF,0XFF,0XFF,0XFF,0XFF,0XFF,0XFF,0XFF,0XFF,
0XFF,0XFF,0XFF,0XFF,0XFF,0XFF,0XFF,0XFF,0XFF,0XFF,0XFF,0XFF,0XFF,0XFF,0XFF,0XFF,
0XFF,0XFF,0XFF,0XFF,0XFF,0XFF,0XFF,0XFF,0XFF,0XFF,0XFF,0XFF,0XFF,0XFF,0XFF,0XFF,
0XFF,0XFF,0XFF,0XFF,0XFF,0XFF,0XFF,0XFF,0XFF,0XFF,0XFF,0XFF,0XFF,0XFF,0XFF,0XFF,
0XFF,0XFF,0XFF,0XFF,0XFF,0XFF,0XFF,0XFF,0XFF,0XFF,0XFF,0XFF,0XFF,0XFF,0XFF,0XFF,
0XFF,0XFF,0XFF,0XFF,0XFF,0XFF,0XFF,0XFF,0XFF,0XFF,0XFF,0XFF,0XFF,0XFF,0XFF,0XFF,
0XFF,0XFF,0XFF,0XFF,0XFF,0XFF,0XFF,0XFF,0XFF,0XFF,0XFF,0XFF,0XFF,0XFF,0XFF,0XFF,
0XFF,0XFF,0XFF,0XFF,0XFF,0XFF,0XFF,0XFF,0XFF,0XFF,0XFF,0XFF,0XFF,0XFF,0XFF,0XFF,
0XFF,0XFF,0XFF,0XFF,0XFF,0XFF,0XFF,0XFF,0XFF,0XFF,0XFF,0XFF,0XFF,0XFF,0XFF,0XFF,
0XFF,0XFF,0XFF,0XFF,0XFF,0XFF,0XFF,0XFF,0XFF,0XFF,0XFF,0XFF,0XFF,0XFF,0XFF,0XFF,
0XFF,0XFF,0XFF,0XFF,0XFF,0XFF,0XFF,0XFF,0XFF,0XFF,0XFF,0XFF,0XFF,0XFF,0XFF,0XFF,
0XFF,0XFF,0XFF,0XFF,0XFF,0XFF,0XFF,0XFF,0XFF,0XFF,0XFF,0XFF,0XFF,0XFF,0XFF,0XFF,
0XFF,0XFF,0XFF,0XFF,0XFF,0XFF,0XFF,0XFF,0XFF,0XFF,0XFF,0XFF,0XFF,0XFF,0XFF,0XFF,
0XFF,0XFF,0XFF,0XFF,0XFF,0XFF,0XFF,0XFF,0XFF,0XFF,0XFF,0XFF,0XFF,0XFF,0XFF,0XFF,
0XFF,0XFF,0XFF,0XFF,0XFF,0XFF,0XFF,0XFF,0XFF,0XFF,0XFF,0XFF,0XFF,0XFF,0XFF,0XFF,
0XFF,0XFF,0XFF,0XFF,0XFF,0XFF,0XFF,0XFF,0XFF,0XFF,0XFF,0XFF,0XFF,0XFF,0XFF,0XFF,
0XFF,0XFF,0XFF,0XFF,0XFF,0XFF,0XFF,0XFF,0XFF,0XFF,0XFF,0XFF,0XFF,0XFF,0XFF,0XFF,
0XFF,0XFF,0XFF,0XFF,0XFF,0XFF,0XFF,0XFF,0XFF,0XFF,0XFF,0XFF,0XFF,0XFF,0XFF,0XFF,
0XFF,0XFF,0XFF,0XFF,0XFF,0XFF,0XFF,0XFF,0XFF,0XFF,0XFF,0XFF,0XFF,0XFF,0XFF,0XFF,
0XFF,0XFF,0XFF,0XFF,0XFF,0XFF,0XFF,0XFF,0XFF,0XFF,0XFF,0XFF,0XFF,0XFF,0XFF,0XFF,
0XFF,0XFF,0XFF,0XFF,0XFF,0XFF,0XFF,0XFF,0XFF,0XFF,0XFF,0XFF,0XFF,0XFF,0XFF,0XFF,
0XFF,0XFF,0XFF,0XFF,0XFF,0XFF,0XFF,0XFF,0XFF,0XFF,0XFF,0XFF,0XFF,0XFF,0XFF,0XFF,
0XFF,0XFF,0XFF,0XFF,0XFF,0XFF,0XFF,0XFF,0XFF,0XFF,0XFF,0XFF,0XFF,0XFF,0XFF,0XFF,
0XFF,0XFF,0XFF,0XFF,0XFF,0XFF,0XFF,0XFF,0XFF,0XFF,0XFF,0XFF,0XFF,0XFF,0XFF,0XFF,
0XFF,0XFF,0XFF,0XFF,0XFF,0XFF,0XFF,0XFF,0XFF,0XFF,0XFF,0XFF,0XFF,0XFF,0XFF,0XFF,
0XFF,0XFF,0XFF,0XFF,0XFF,0XFF,0XFF,0XFF,0XFF,0XFF,0XFF,0XFF,0XFF,0XFF,0XFF,0XFF,
0XFF,0XFF,0XFF,0XFF,0XFF,0XFF,0XFF,0XFF,0XFF,0XFF,0XFF,0XFF,0XFF,0XFF,0XFF,0XFF,
0XFF,0XFF,0XFF,0XFF,0XFF,0XFF,0XFF,0XFF,0XFF,0XFF,0XFF,0XFF,0XFF,0XFF,0XFF,0XFF,
0XFF,0XFF,0XFF,0XFF,0XFF,0XFF,0XFF,0XFF,0XFF,0XFF,0XFF,0XFF,0XFF,0XFF,0XFF,0XFF,
0XFF,0XFF,0XFF,0XFF,0XFF,0XFF,0XFF,0XFF,0XFF,0XFF,0XFF,0XFF,0XFF,0XFF,0XFF,0XFF,
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
int main(void)
{
//    bsp_board_init(BSP_INIT_LEDS);

    APP_ERROR_CHECK(NRF_LOG_INIT(NULL));
    NRF_LOG_DEFAULT_BACKENDS_INIT();

    spi_gpio_init();

    /**/
    nrf_drv_spi_config_t spi_config = NRF_DRV_SPI_DEFAULT_CONFIG;
    spi_config.ss_pin   = SPI_SS; //NRFX_SPIM_PIN_NOT_USED; //  //SPI_SS_PIN;
    spi_config.miso_pin = SPI_MISO; //SPI_MISO_PIN;
    spi_config.mosi_pin = SPI_MOSI; //SPI_MOSI_PIN;
    spi_config.sck_pin  = SPI_SCK;  //SPI_SCK_PIN;
    spi_config.frequency = NRF_DRV_SPI_FREQ_1M;
    APP_ERROR_CHECK(nrf_drv_spi_init(&spi, &spi_config, spi_event_handler, NULL));

    NRF_LOG_INFO("SPI example started.");

    EPD_Init();


  DBG("%s:%d\r\n", __func__, __LINE__);

    DBG("clear...\r\n");
    EPD_Clear();
    SdkDelayMs(500);

  int i;
/*
  u8 c = LUTDefault_part[0];
  
  EPD_SendCommand(c);
  
  for(i = 1; i < sizeof(LUTDefault_part); i++){
    c = LUTDefault_part[i];
    EPD_SendData(c);
  }
*/
    EPD_SetLut();
    SdkDelayMs(100);
    EPD_Clear();
    SdkDelayMs(500);
//    EPD_SetPartialLut();
//    EPD_Clear();
  
  int tmo = 2; //100;
  while(tmo--){
  DBG("%s:%d\r\n", __func__, __LINE__);
  
  pic_display_4bit();
  
/**/
//  if(tmo % 4 == 0){
//  }
//  else
    EPD_SetPartialLut();
    SdkDelayMs(100);
    
//    if(_disp_cntr <= 0){
//          EPD_SetLut();
//    }

    EPD_SendCommand(DISPLAY_REFRESH);
    EPD_WaitUntilIdle();
    SdkDelayMs(500);
    
    EPD_SendCommand(DISPLAY_REFRESH);
    EPD_WaitUntilIdle();
    SdkDelayMs(100);
/**/
/*

    EPD_SendCommand(DISPLAY_REFRESH);
    EPD_WaitUntilIdle();
    SdkDelayMs(100);

    EPD_SendCommand(DISPLAY_REFRESH);
    EPD_WaitUntilIdle();
    SdkDelayMs(100);
*/
    SdkDelayMs(1000);
}
    

    Paint_NewImage(screen, EPD_WIDTH, EPD_HEIGHT, 90, WHITE);
    Paint_SelectImage(screen);

    DBG("Drawing:BlackImage\r\n");
    Paint_Clear(WHITE);
    Paint_DrawPoint(10, 80, BLACK, DOT_PIXEL_1X1, DOT_STYLE_DFT);
    Paint_DrawPoint(10, 90, BLACK, DOT_PIXEL_2X2, DOT_STYLE_DFT);
    Paint_DrawPoint(10, 100, WHITE, DOT_PIXEL_3X3, DOT_STYLE_DFT);
    Paint_DrawLine(20, 70, 70, 102, BLACK, LINE_STYLE_SOLID, DOT_PIXEL_1X1);
    Paint_DrawLine(70, 70, 20, 102, BLACK, LINE_STYLE_SOLID, DOT_PIXEL_1X1);
    Paint_DrawRectangle(20, 70, 70, 102, BLACK, DRAW_FILL_EMPTY, DOT_PIXEL_1X1);
    Paint_DrawRectangle(80, 70, 103, 102, BLACK, DRAW_FILL_FULL, DOT_PIXEL_1X1);
    Paint_DrawCircle(45, 95, 20, BLACK, DRAW_FILL_EMPTY, DOT_PIXEL_1X1);
    Paint_DrawCircle(105, 95, 20, WHITE, DRAW_FILL_FULL, DOT_PIXEL_1X1);
    Paint_DrawLine(85, 95, 125, 95, BLACK, LINE_STYLE_DOTTED, DOT_PIXEL_1X1);
    Paint_DrawLine(105, 75, 105, 115, BLACK, LINE_STYLE_DOTTED, DOT_PIXEL_1X1);

    Paint_DrawString_XBM(0, 0, "01234", font_DINNextW1G_Light_58, BLACK, WHITE);

//    Paint_DrawString_EN(10, 0, "waveshare", &Font16, BLACK, WHITE);
//    Paint_DrawString_EN(10, 20, "hello world", &Font12, WHITE, BLACK);
//    Paint_DrawNum(10, 33, 123456789, &Font12, BLACK, WHITE);
//    Paint_DrawNum(10, 50, 987654321, &Font16, BLACK, WHITE); //WHITE, BLACK);

  DBG("%s:%d\r\n", __func__, __LINE__);
    EPD_Display(screen);

  DBG("%s:%d\r\n", __func__, __LINE__);

//    EPD_Sleep();

  //int 
    i = 0;

    EPD_Clear();
    while (1)
    {
        char s[20];
        // Reset rx buffer and transfer done flag
//        memset(m_rx_buf, 0, m_length);
        //spi_xfer_done = false;

//        APP_ERROR_CHECK(nrf_drv_spi_transfer(&spi, m_tx_buf, m_length, m_rx_buf, m_length));

     //   while (1) //!spi_xfer_done)
        {
            //__WFE();
            SdkDelayMs(1000);
            Paint_Clear(WHITE);
            snprintf(s, sizeof(s), "%02X:%02x", i, i);
            Paint_DrawString_XBM(30, 0, s, 
                              //font_BNKGOTHM_60,
                              //font_BNHRDFAN_50,
                              //font_GOST_A__62,
                              //font_TMVinograd_70,

//font_ACLine_100,
//font_CaviarDreams_100, //!
//font_Lasco_100,
//font_OpenSans_100, //+-
//font_Ubuntu_100, //+-
//font_Alexander_100, //+-
//font_BNHRDMBI_100, //?
//font_LCD_100, //+-
//font_Raleway_100,
//font_Zhizn_100,
//font_ALLEGRON_100, // )
//font_BNHRDMOB_100, //+
//font_RobotoCondensed_100, //+
//font_Bender_100, //+-

                              //font_BNKGOTHM_100,
//font_gnyrwn971_100, //++
font_LEngineer_100, //++ but 20% bigger
//font_TMVinograd_100,
//font_BNHRDFAN_100,
//font_GOST_A__100, //++ 10% bigger
//font_NotoSans_100,

                              //font_LCD_124, 
                              //font_DINNextW1G_Light_58,
                              BLACK, WHITE);
            EPD_Display(screen);

            i++;
        }

//        NRF_LOG_FLUSH();

//        bsp_board_led_invert(BSP_BOARD_LED_0);
        nrf_delay_ms(200);
    }
}

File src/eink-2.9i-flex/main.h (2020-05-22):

#ifndef _MAIN_H_
#define _MAIN_H_


#include "nrf_log.h"
#include "nrf_log_ctrl.h"
#include "nrf_log_default_backends.h"


#define SPI_MISO  16
#define SPI_MOSI  20
#define SPI_SCK   19
#define SPI_SS    17

#define EINK_RES  23
#define EINK_BUSY 22
#define EINK_DC   24

#define UART_RX   6
#define UART_TX   8

#define NFC1 9
#define NFC2 10


#define EPD_RST_PIN EINK_RES
#define EPD_DC_PIN  EINK_DC
#define EPD_BUSY_PIN EINK_BUSY

typedef unsigned char  UBYTE;
typedef unsigned short UWORD;
typedef unsigned int   UDOUBLE;
//typedef unsigned char UBYTE;

#undef NRF_LOG_INFO
#define NRF_LOG_INFO(...)

#define Debug(...) NRF_LOG_INFO(__VA_ARGS__)

#define DBG(...)

void GPIO_SetBits(int pin);
void GPIO_ResetBits(int pin);

int GPIO_ReadBit(int pin);

void SdkDelayMs(int time);

void SPI_SendReceiveData(UBYTE* tx_buf, int tx_cnt);

#endif //_MAIN_H_

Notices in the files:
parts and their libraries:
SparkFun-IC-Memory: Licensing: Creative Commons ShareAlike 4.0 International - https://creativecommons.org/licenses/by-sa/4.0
